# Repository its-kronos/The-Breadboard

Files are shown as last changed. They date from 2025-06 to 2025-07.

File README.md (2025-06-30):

# The Breadboard+

PCB_FRONT

PCB_BACK

# What is it?
- The Breadboard+ is a custom RP2040 devboard in the ***shape of bread*** and fun decorations on both the front and back, making it slightly bigger than others in return for a much nicer look.
- This board should have nearly everything that would be needed for any IOT project, including a ***USBC connection, 24 GPIO pins (4 analog), and even WIFI connectivity*** through a secondary microcontroller on the board (the ESP-32 WROOM C3)
- Unfortunately, the WIFI connection must sacrifice 1 out of 2 UART connections when in use, but other than that, the sky's the limit!
# Why did I design it?
- Many designs for devboards like the PI Pico and other competitors have been designed to be as compact as possible, but this naturally limits space for creativity and art on the PCB itself. Rather than make something with the constraint of size, I decided to add as many features that I saw reasonable without removing too much.
- After previously designing a keyboard PCB with a bare RP2040 chip, I decided that creating a custom devboard would be a good way for me to practice reading documentation and extend upon the skills developed during that previous project.



# Surprises
- When I first started routing the PCB, I didn't realize how thick the traces would need to be to insure a 90 ohm impedence on the USB data lines, which is called for by USB standards. This posed quite a difficulty because the design rules checker (DRC) kept on warning that the clearence between traces was too small, and it took me a good amount of time to learn how to assign different rules for different netlists (AKA connected parts).



- Something that was pretty surprising, but not much of a challenge for me to work around was the cost of PCBA for custom devboards
- Naturally, custom devboards would require many parts that are considered "extended" requiring 3 dollars per type of component for assembly.
- I had already tried choosing the best parts for their task (most of which were either basic parts or extended preferred)



- With this amount of extended parts (the 27 ohm resistor being extended preferred), the price for PCBA ended up being quite high


# PCB
- There were some moments of learning, but since I already created a PCB for a bare-chip custom keyboard, this process was pretty fast comparatively.







# CAD
- I unfortunately feel that anything in a single-color print wouldn't really look good and instead completely hide the purpose that I designed this PCB for.
- The PCB was designed to look creative, but printing a case would would hide these qualities, and the best case that I see coming out of it would be copying the breadshape from an SVG and effortlessly extruding it as well as adding holes for screws

# BOM

| VENDOR | ITEM | PRICE(USD) | SHIPPING | PCS | CNT | REMARKS 1 | REMARKS 2 |
|---|---|---|---|---|-----|---|---|
| | | | | | | | |
| JLCPCB | | | | | | | |
| | PCB | 3.2 | | 5 | 1 | LEAD-FREE HASL | |
| | PCBA | 42.43 | | 2 | 1 | Only for SMD | |
| | | | 26.83 | | | UPS DDP to avoid customs headache (cheapest shipping available with DDP) | Detailed by the cost-optimizing guide |
| | | | 25.1 | | | Taxes & Fees | |
| | | | | | | | |
| | TOTAL | 97.56 | | | | | |
| | | | | | | | |
| ALIEXPRESS | | | | | | | |
| | [HEADERS](https://www.aliexpress.us/item/3256807894655866.html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) | 2.13 | | 10 1x40 Female 10 1x40 Male | 1 | | |
| | [BUTTONS](https://www.aliexpress.us/item/3256804068199319.html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) | 2.77 | | 20 | 1 | 6x6x4.3mm | EXCLUDED |
| | | | 1.99 | | | | |
| | | | | | | | |
| | TOTAL | 4.12 | | | | | |
| | | | | | | | |
| | | | | | | | |
| TAXES | | (Have way more than enough needed for ALIEXPRESS) | | | | | |
| | | | | | | | |
| TOTAL | 101.68 | | | | | | |

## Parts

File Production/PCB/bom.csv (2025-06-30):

Designator | Footprint | Quantity | Value | LCSC Part #
C1, C10, C11, C12, C13, C14, C15, C20, C6, C7, C8, C9 | 402 | 12 | C100n | C1525
C2, C3 | 402 | 2 | C1u | C52923
C21, C22 | 402 | 2 | C15p | C1548
C4, C5 | 402 | 2 | C10u | C15525
J1 | Korean Hroparts Elec - Type C 31 M 12 - 16P - USB 2.0 | 1 | ~ | C165948
J2 | PinHeader_2x25_P2.54mm_Vertical | 1 | Conn_02x25_Odd_Even | DNF
J3 | PinHeader_1x03_P2.54mm_Vertical | 1 | Conn_01x03_Pin | DNF
R1, R4, R6 | 402 | 3 | R1k | C11702
R2, R3 | 402 | 2 | R5.1k | C25905
R7, R8 | 603 | 2 | R27 | C25190
SW1, SW2 | SW_PUSH_6mm | 2 | SW_Push | DNF
U1 | QFN-56-1EP_7x7mm_P0.4mm_EP3.2x3.2mm | 1 | RP2040 | C2040
U2 | SOT-23-6 | 1 | USBLC6-2SC6 | C7519
U3 | SOT-223-3_TabPin2 | 1 | NCP1117-1.5_SOT223 | C26537
U4 | SOIC-8_5.3x5.3mm_P1.27mm | 1 | W25Q128JVS | C97521
U5 | ESP32-C3-WROOM-02 | 1 | ESP32-C3-WROOM-02 | C2934560
Y1 | Crystal_SMD_3225-4Pin_3.2x2.5mm | 1 | Crystal_GND24 | C20625731

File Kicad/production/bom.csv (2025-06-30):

Designator | Footprint | Quantity | Value | LCSC Part #
C1, C10, C11, C12, C13, C14, C15, C20, C6, C7, C8, C9 | 0402 | 12 | C100n
C2, C3 | 0402 | 2 | C1u
C21, C22 | 0402 | 2 | C15p
C4, C5 | 0402 | 2 | C10u
J1 | Korean Hroparts Elec - Type C 31 M 12 - 16P - USB 2.0 | 1 | ~
J2 | PinHeader_2x25_P1.00mm_Vertical | 1 | Conn_02x25_Odd_Even
J3 | PinHeader_1x03_P1.00mm_Vertical | 1 | Conn_01x03_Pin
R1, R4, R6 | 0402 | 3 | R1k
R2, R3 | 0402 | 2 | R5.1k
R7, R8 | 0603 | 2 | R27
SW1, SW2 | SW_PUSH_6mm | 2 | SW_Push
U1 | QFN-56-1EP_7x7mm_P0.4mm_EP3.2x3.2mm | 1 | RP2040
U2 | SOT-23-6 | 1 | USBLC6-2SC6
U3 | SOT-223-3_TabPin2 | 1 | NCP1117-1.5_SOT223
U4 | SOIC-8_5.3x5.3mm_P1.27mm | 1 | W25Q128JVS
U5 | ESP32-C3-WROOM-02 | 1 | ESP32-C3-WROOM-02
Y1 | Crystal_SMD_3225-4Pin_3.2x2.5mm | 1 | Crystal_GND24

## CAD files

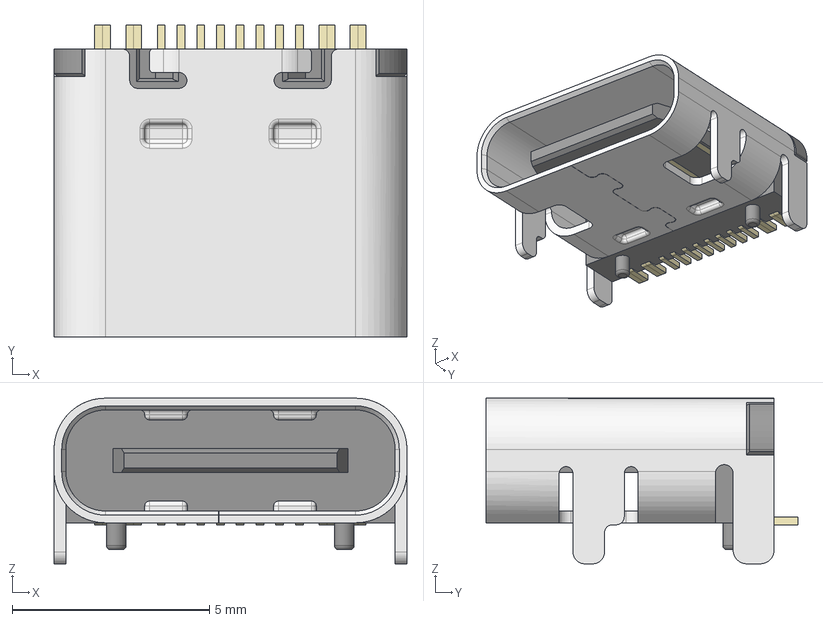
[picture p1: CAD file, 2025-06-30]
Kicad/Models/USB/Type-C/Korean_Hroparts-16P-Female.step
8.95 x 7.90 x 4.20 mm

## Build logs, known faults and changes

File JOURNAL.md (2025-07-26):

# Journal

# Information
- Title: "The Breadboard"
- Author: An. D. (its_kronos)
- Description: Breadboard, but microcontroller (AKA custom devboard) *probably change later*
- Creation Date: 6/24/2025
- Total Time (before building): 13h 

# 6/24/2025

- Did a lot of unfocused researched, and also hopped in a huddle (voicechat) with @Cyao and asked a lot of questions about incorperating RF into a design
- Confirmed what exactly I wanted to build, which would be a devboard with the 2350B MCU for maximum GPIO and a routing challenge. I would also want to include WIFI connectivity like the PI Pico W, which would make it useful in projects that require things like API calls based on peripherals.

**Time: Untimed, especially since this research was unfocused**

# 6/25/2025

* did some research about the PI235x chips with the hardware guide
* downloaded footprint for RP2350B
* created schematic part for the VREG



* made custom footprint for the inductor, which recommended a specific part to ensure correct coiling for minimal interferance



* sourced components needed for the VREG
* Made schematic for and sourced all parts needed for the USB connection, including parts like an LDO, which was pretty easy since this is the second time doing it for me



* made the schematic for and sourced parts required for decoupling capacitors for the power pins



* in the hardware guide for the rp235x series chips, it includes a resistor with value 0 ohms for the QSPI_SS pin, so I researched why there wasn't a direct connection and learned that it can be used as a "jumper wire" on a pcb



* finished schematic for the flash memory for the chip



* finished schematic for the crystal



- And here is the running component list (most of which are either basic or extended preferred parts, which took a bit of time to find, but nothing too serious)!



- overall this part of the schematic was pretty easy and didn't require too much challenge, and I believe that the main part of the challenge will come when actually routing the board

**TIME: 2h30m**

* I was done with the RP chip wiring from last session, so now the next logical step would be for me to wire the pin headers, but I was unable to decide which nets/GPIOs should go to which pin on the headers, but I did add a boot button to RUN and some more headers for debugging



* I instead decided to try and add the RF/WIFI IC for the wifi support that I wanted to add, and I looked at the documentation for the CC2500 transceiver by TI, but this only led to me being increasingly confused and spending a lot of time pretty much getting nowhere
* My main question would be how the RP2350 chip would communicate with the CC2500 to control what packets of data or being sent out, or what mode the chip is in.

**time: 1h**

# 6/26/2025

* Using another MCU (the wroom c3) as a way to add wifi connectivity at the cost of 1 UART interface when being used
* decided to start routing the board so that I can know which pins are ideal to use for what purpose, so i assigned all the footprints



* I had trouble routing because the pins were too close together, so I changed the main MCU to the RP2040 and double checked that everything was according to the different hardware guide



* i had to replace a few of the parts of the schematics to fit with the RP2040, and then I reselected all the footprints and started routing



* here is the routing I have so far, and I tried my best to make sure that sensitive components would be out of the way from traces that would disrupt them, but what I did realize is that I need to find a new ESD protection IC since the current one would pretty much make it impossible to route
* It was pretty time consuming due to the numerous decoupling capacitors needed in many locations, and I might have to compromise on a few of them 

**Time: 2h**

* found a new, better ESD protection that would be easier to route and even cheaper too
* restarted routing because I didn't plan for the ESD protection to be this big



* placed everything except the connectors, which could go almost anywhere on the board (this took a while to get everything seemingly spaced out well enough but I feel that it's pretty good)



* finished routing everything for the main part of the board (meaning excluding WIFI and GPIO), which took around an hour due to slight repositioning and trying to space out signals when possible, which was mostly a new-ish concept for me, which I only slight skimmed over for a keyboard I made prior.



**TIME:2h**

# 6/27/2025

* rerouted the differential pair so that it actually has a 90 ohm differential impedance which is called for by USB protocol, and this took a long while because I didn't really know how to get the DRC to stop screaming at me for having too small clearances, but this was fixed by just assigning different netclasses.



* routed the secondary MCU completely, although i am worried a bit about the TX and RX traces for it interfering, so if I have space in the future after routing GPIO, I'll try to separate them.



* moved some components in order to have a much slimmer layout, and then proceeded to route the GPIO pins, which for now was pretty easy (except for deciding which GPIO pin should be where), but I have a feeling that the last few GPIOs might be a lot more difficult



TIME: 2h 15m

* I finished up routing everything which was surprisingly easy due to the amount of excess space I had. It was just a bit time consuming to figure out the best way to route everything to minimize crossovers
* I was a bit worried about the crystal being close to GPIO traces, but somebody also part of Hackclub told me that it's most likely fine due to the grounding vias, but I did also move it closer to the XTAL pins on the MCU
* Added some art on the front and back C:









* All that's really left for me would be to draft up some code and maybe (?) create a case (probably not since single-color PLA wouldn't really look that great for it)

**time: 1h45m** 

# 6/28/2025

- Just drafted up some code to be able to flash the second MCU for the WIFI connection by forwarding USB signals through UART
- Started creating stuff like the BOM and will finish a description in the README with pictures (This will most likely be untimed)

**TIME: 30m**

# 6/30/25

- Turns out I used the wrong footprint for the pin headers, so I had to restart routing them and make the board bigger, which wasn't much of a challenge since the routing was pretty similar, but still a bit time consuming.
  


- Anyways here is the (hopefully) final version
  



**TIME: 1h**

# 7/25/25

- Started by figuring out how to get circuit python on the RP2040, which required me to use linux to create a custom devboard config
- Since I used windows, I had to research about virtual machines and had to get linux running with everything needed for circuit python, which was quite a challenge due to me not really using terminal before



- However, after flashing circuit python, it didn't allow me to use the TX and RX pins I needed, so then I tried micropython, which also didn't work!



- I decided to then try circuit python again, but this ultimately failed, and I realized that the RP2040 chip doesn't support UART on *every* single pin, only some of them for TX and RX, so I then learned that I needed to use PIO

**Time: 6.25h**

- I implemented PIO and was able to flash and read the MCU





- However, it did take me a while to learn that I had to use a much slower bauderate than default, and trying to use the normal one just resulted in no connection to esptool

  **TIME: 2h**

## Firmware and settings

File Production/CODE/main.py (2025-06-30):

# first install circuit python please!

import board
import usb_cdc
import busio as bus
import digitalio as IO
import time

usb_cdc.enable(console = True, data = True)

usb = usb_cdc.data
uart = bus.UART(tx=board.D2, rx=board.D1, baudrate=115200)

#setting up pins used for bootloader
IO2 = IO.DigitalInOut(board.D0)
IO8 = IO.DigitalInOut(board.D4)
IO9 = IO.DigitalInOut(board.D5)
EN = IO.DigitalInOut(board.D3)

IO2.direction = IO.Direction.OUTPUT
IO8.direction = IO.Direction.OUTPUT
IO9.direction = IO.Direction.OUTPUT
EN.direction = IO.Direction.OUTPUT

#setting bootloader mode to UART and resetting MCU
IO2.value = True
IO8.value = True
IO9.value = False

EN.value = False
EN.value = True

while True:
    if usb.in_waiting>0:
        data = usb.read(usb.in_waiting)
        uart.write(data)


    if uart.in_waiting>0:
        data = uart.read(uart.in_waiting)
        usb.write(data)

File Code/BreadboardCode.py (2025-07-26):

# first install circuit python please!
BOOTLOADER = True


import board
import usb_cdc
import adafruit_pio_uart as bus
import digitalio as IO
import time

usb = usb_cdc.data
uart = bus.UART(tx=board.GP2, rx=board.GP1, baudrate=9600)

#setting up pins used for bootloader
IO2 = IO.DigitalInOut(board.GP0)
IO8 = IO.DigitalInOut(board.GP4)
IO9 = IO.DigitalInOut(board.GP5)
EN = IO.DigitalInOut(board.GP3)

IO2.direction = IO.Direction.OUTPUT
IO8.direction = IO.Direction.OUTPUT
IO9.direction = IO.Direction.OUTPUT
EN.direction = IO.Direction.OUTPUT

#setting bootloader mode to UART and resetting MCU

if BOOTLOADER:
    IO2.value = True
    IO8.value = True
    IO9.value = False

    EN.value = False
    time.sleep(0.05)
    EN.value = True
    time.sleep(0.05)


print("Communication started!")
while True:
    if usb.in_waiting>0:
        #print("USB data found")
        data = usb.read(usb.in_waiting)
        #print(data)
        #print("\n")
        uart.write(data)


    if uart.in_waiting>0:
        #print("UART data found")
        data = uart.read(uart.in_waiting)
        #print(data)
        #print("\n")
        usb.write(data)

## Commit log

2025-06-28 Update README.md - ADD BOM
2025-06-29 Update README.md - completed the readme, updated BOM to include DDP shipping
2025-06-30 add entire project
    [BOM.csv, Breadboard.kicad_sch, Korean_Hroparts-16P-Female.step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]
2025-06-30 slightly change up PCB for wider power traces (5 minute thing so not tracked)
2025-06-30 add different footprints, slightly modify BOM
    [BOM.csv, bom.csv, positions.csv]
2025-06-30 Update README.md - modify bom
2025-06-30 removed G*** from silkscreen
2025-06-30 change pcb color
2025-07-01 added tooling holes to pcb
